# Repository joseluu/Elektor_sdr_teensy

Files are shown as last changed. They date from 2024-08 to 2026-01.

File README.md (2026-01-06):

### SDR front end for teensy and teensy audio

This frontend board stacks on top of a teensyaudio board which iself is stacked on the teensy.

<p align="center">
  <table style="width:100%">
    <tr>
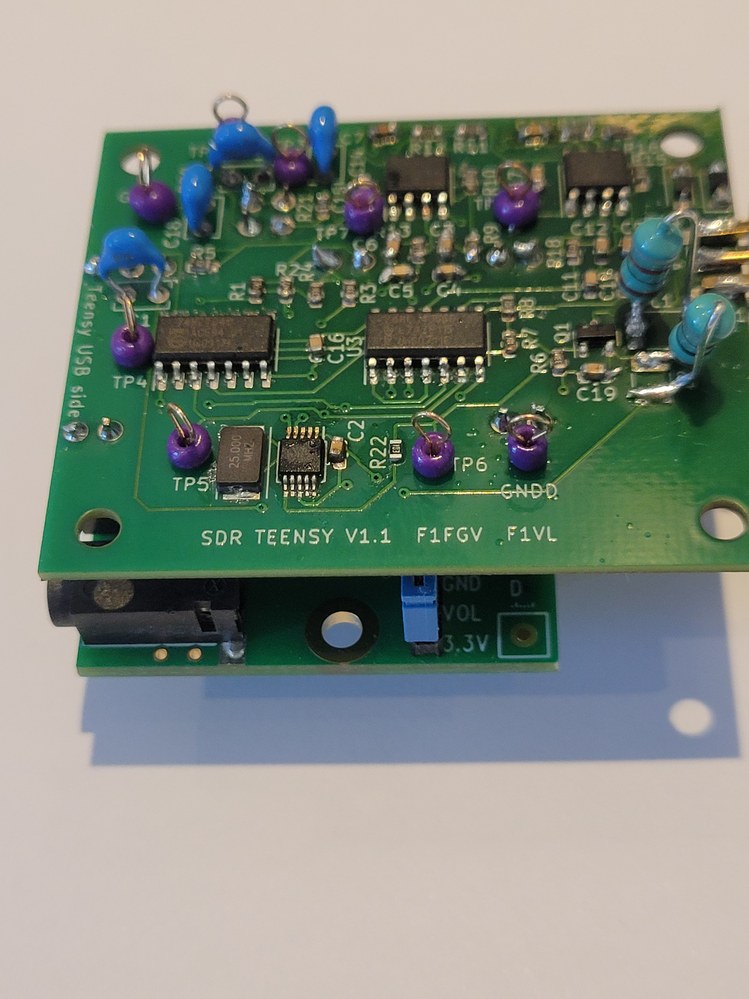
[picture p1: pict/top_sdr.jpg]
top view
      <td></td>
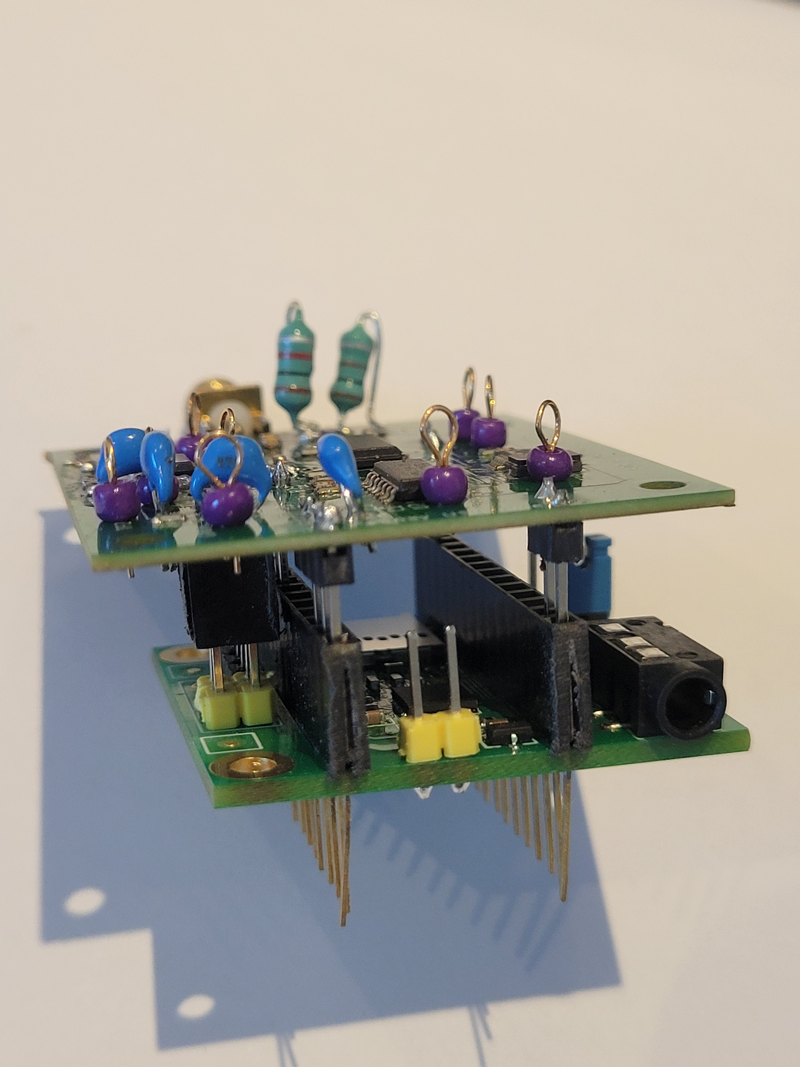
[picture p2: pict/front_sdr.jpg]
front view
      <td></td>
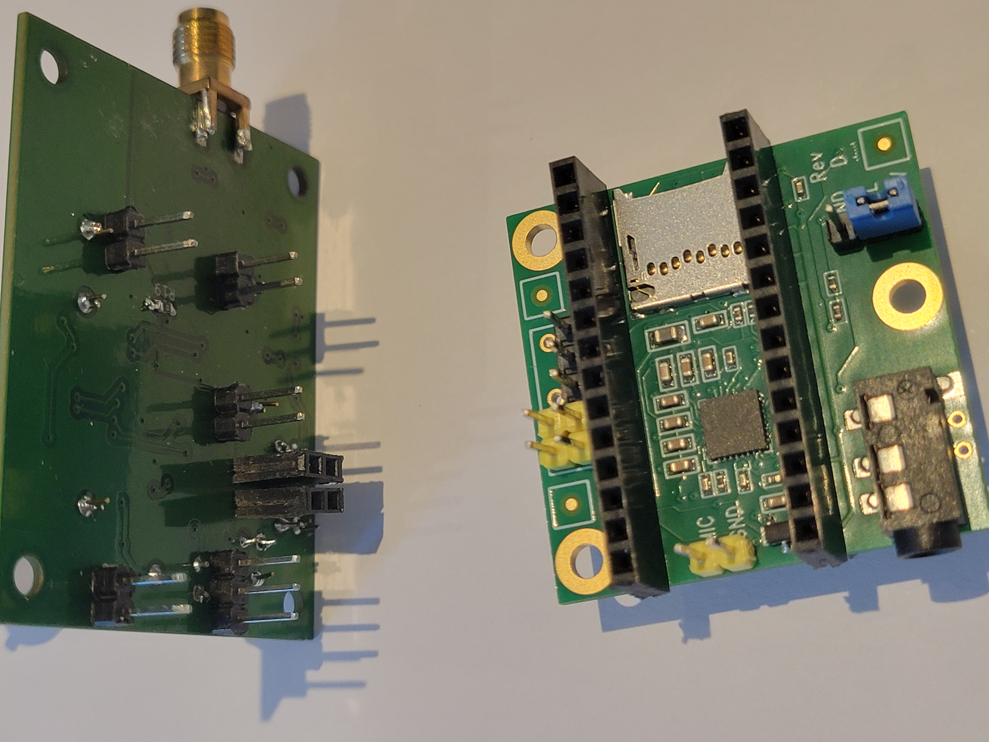
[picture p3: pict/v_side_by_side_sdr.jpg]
side by side view 1
      <td></td>
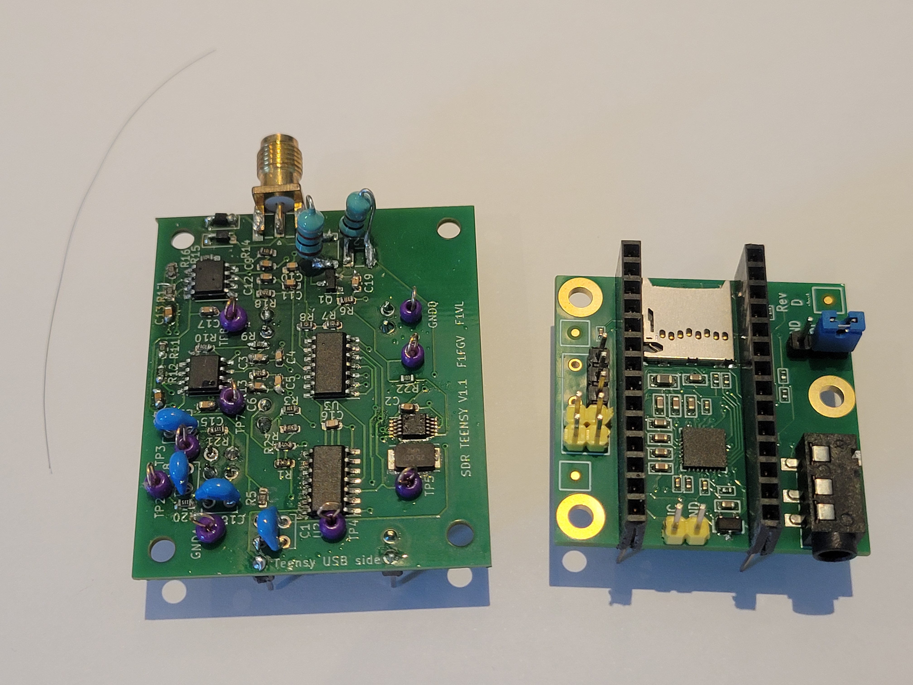
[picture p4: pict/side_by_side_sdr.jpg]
side by side view
      <td></td>
    </tr>
  </table>
</p>

Teensy 4.0 is used, schematic is heavily inspired by the Elektor board: https://www.elektormagazine.fr/labs/software-defined-radio-sdr-shield-for-arduino-150515-1

The differences are:

The frequency is not divided by 4 to make quadrature signals (no 7474 flipflops), rather the quadrature will have to be generated by the si5351.
A provision for an external oscillator input is made (V1.0 only), it uses a separate SMA

PCB layout attempts to minimize noise with separate ground planes for digital and analog

Versions (V2.0 is in its own branch):

<p align="center">
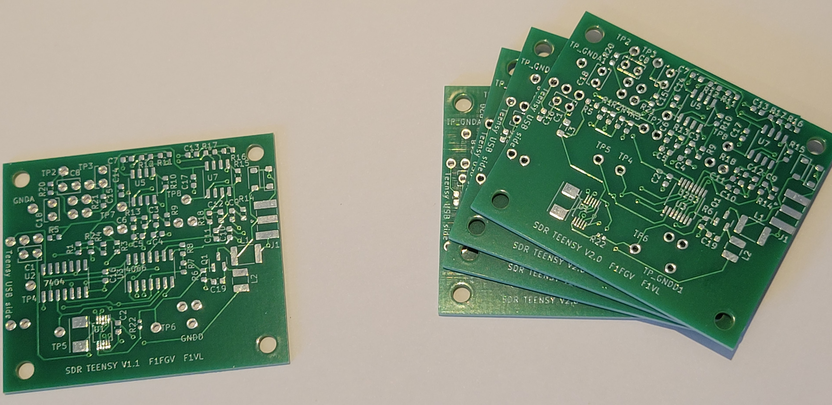
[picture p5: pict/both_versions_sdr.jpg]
both versions pcb
</td>
</p>

V 1.1 fixes a cabling error to two of the 6022 op-amps, removes the external oscillator input, internally connects the 3rd output of the si5351 frequency synthetiser to the input allowing fot tests and calibration of the signal path

V 1.1 uses a 74HC4066 multiplexer and is good to 30MHz, has a cabling error underneath where the zero ohm resistor connecting the 2 ground plane is not connected on one side.

V 2.0 uses a SN74CBTL3253 and should be good to 150MHz (work in progress, not tested yet)

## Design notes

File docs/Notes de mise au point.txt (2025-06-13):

Notes de mise au point:

Injecter signal de CLK2 sur l'entrée du récepteur, fréquence décalée de 50kHz, 
avec 50 db (1/300) d'atténuation -> 100mV crête (triangle) sur chacune des 2 entrées du shield audio

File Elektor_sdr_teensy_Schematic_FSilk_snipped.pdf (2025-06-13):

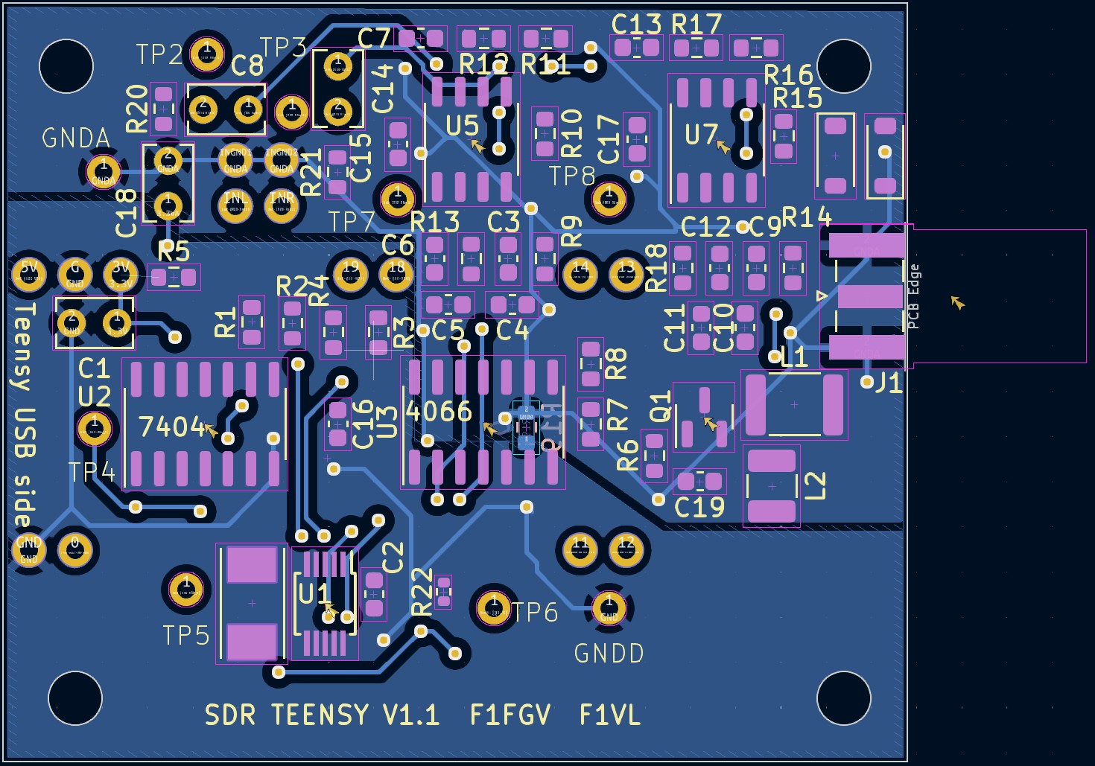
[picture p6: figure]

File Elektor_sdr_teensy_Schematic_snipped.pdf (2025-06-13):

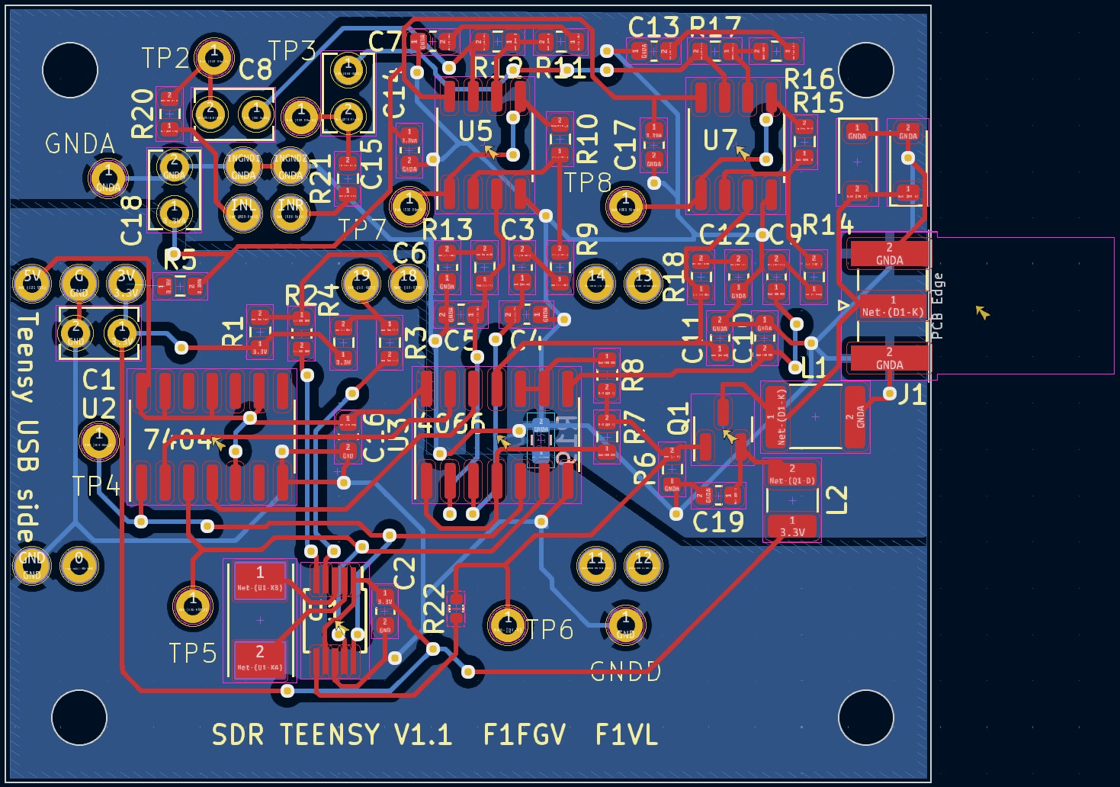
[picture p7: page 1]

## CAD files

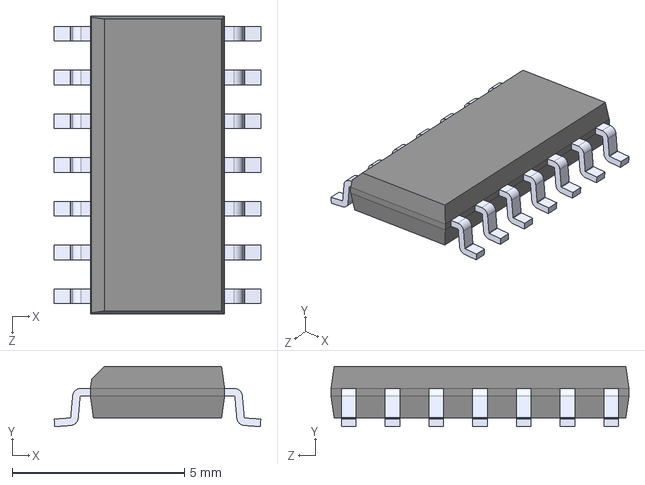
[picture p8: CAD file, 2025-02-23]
kicad_download/74HC4066D_653.step
6.00 x 1.75 x 8.65 mm

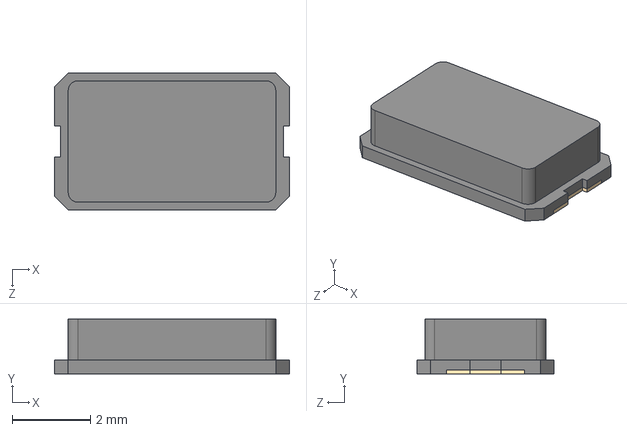
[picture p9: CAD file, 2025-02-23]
kicad_download/ABM7-16.000MHZ-D2Y-T.step
6.00 x 1.40 x 3.50 mm

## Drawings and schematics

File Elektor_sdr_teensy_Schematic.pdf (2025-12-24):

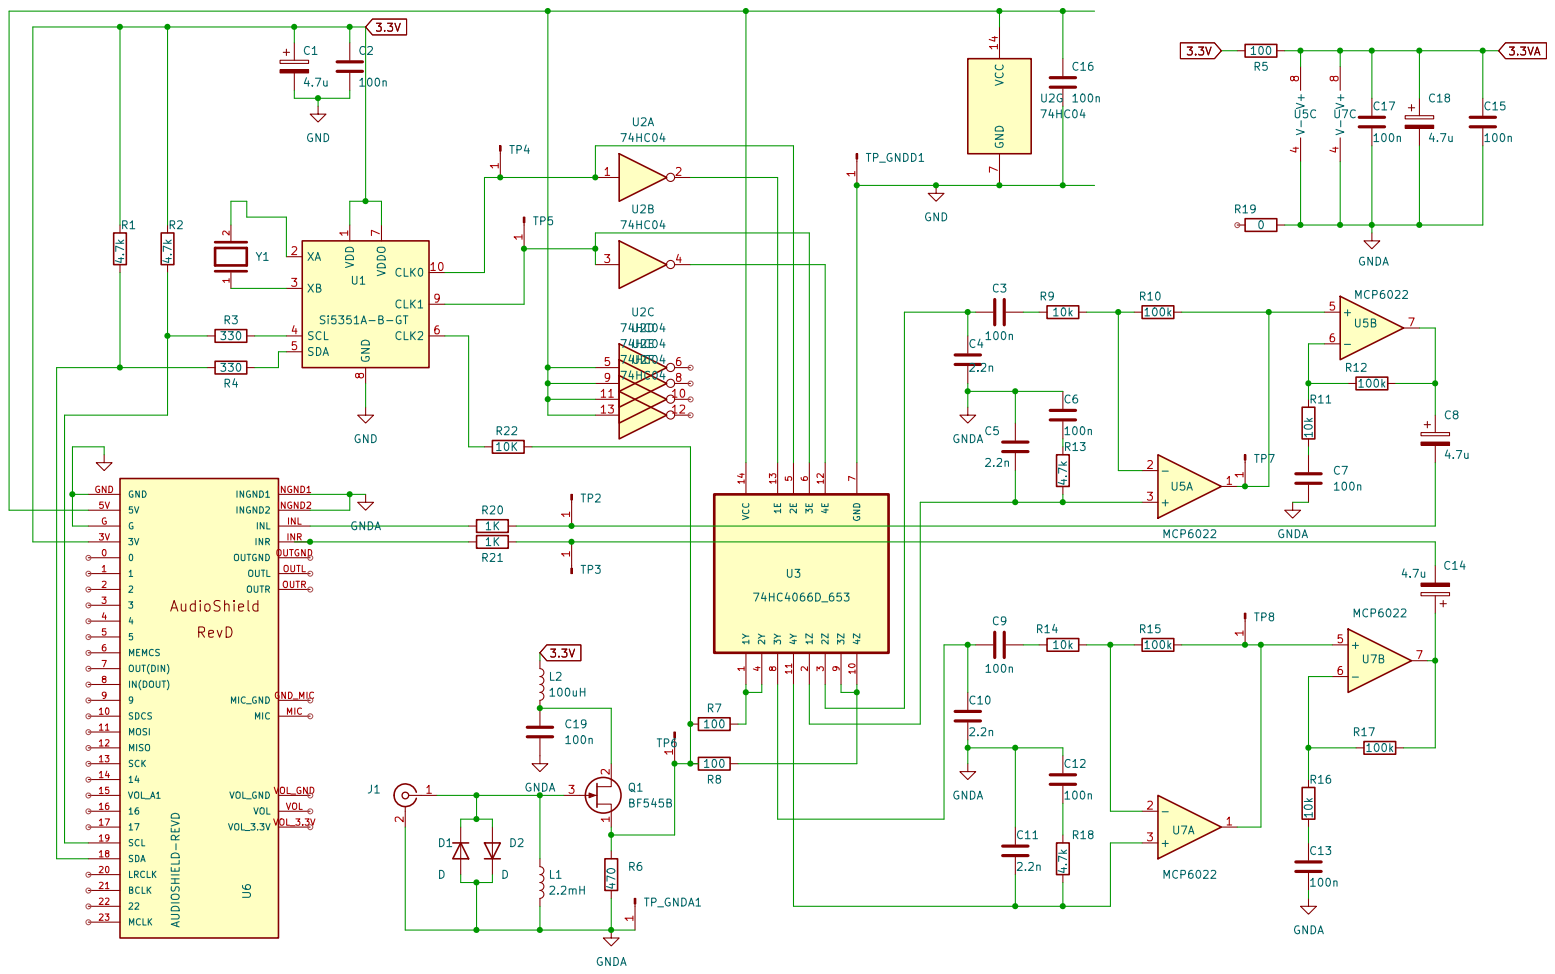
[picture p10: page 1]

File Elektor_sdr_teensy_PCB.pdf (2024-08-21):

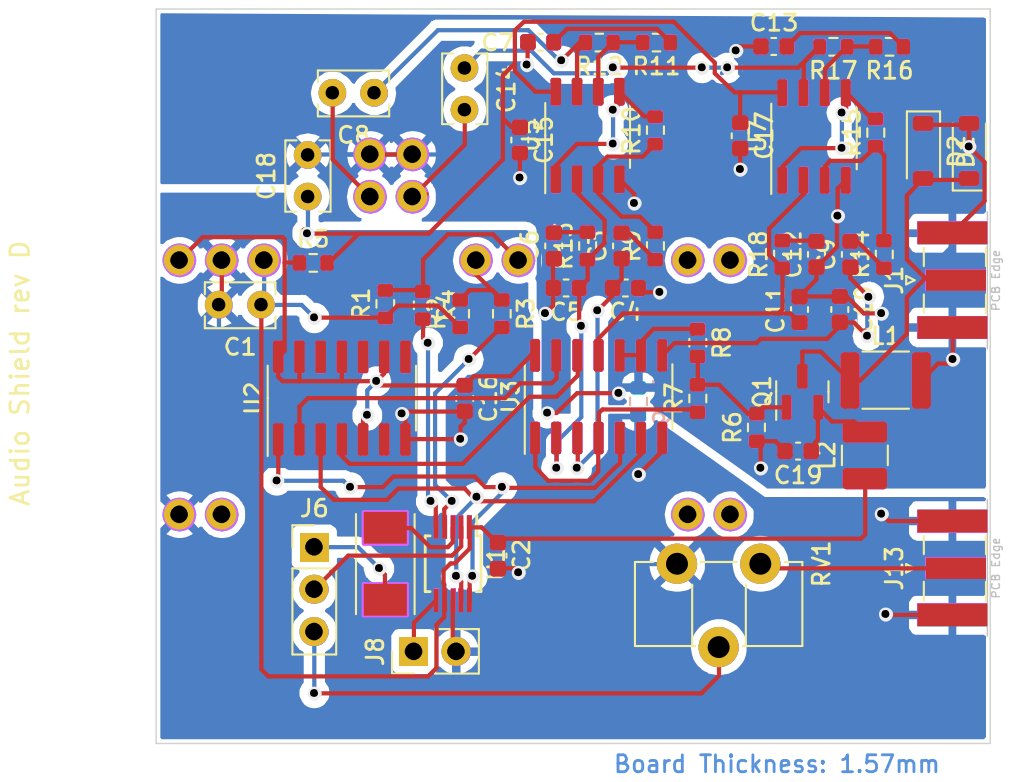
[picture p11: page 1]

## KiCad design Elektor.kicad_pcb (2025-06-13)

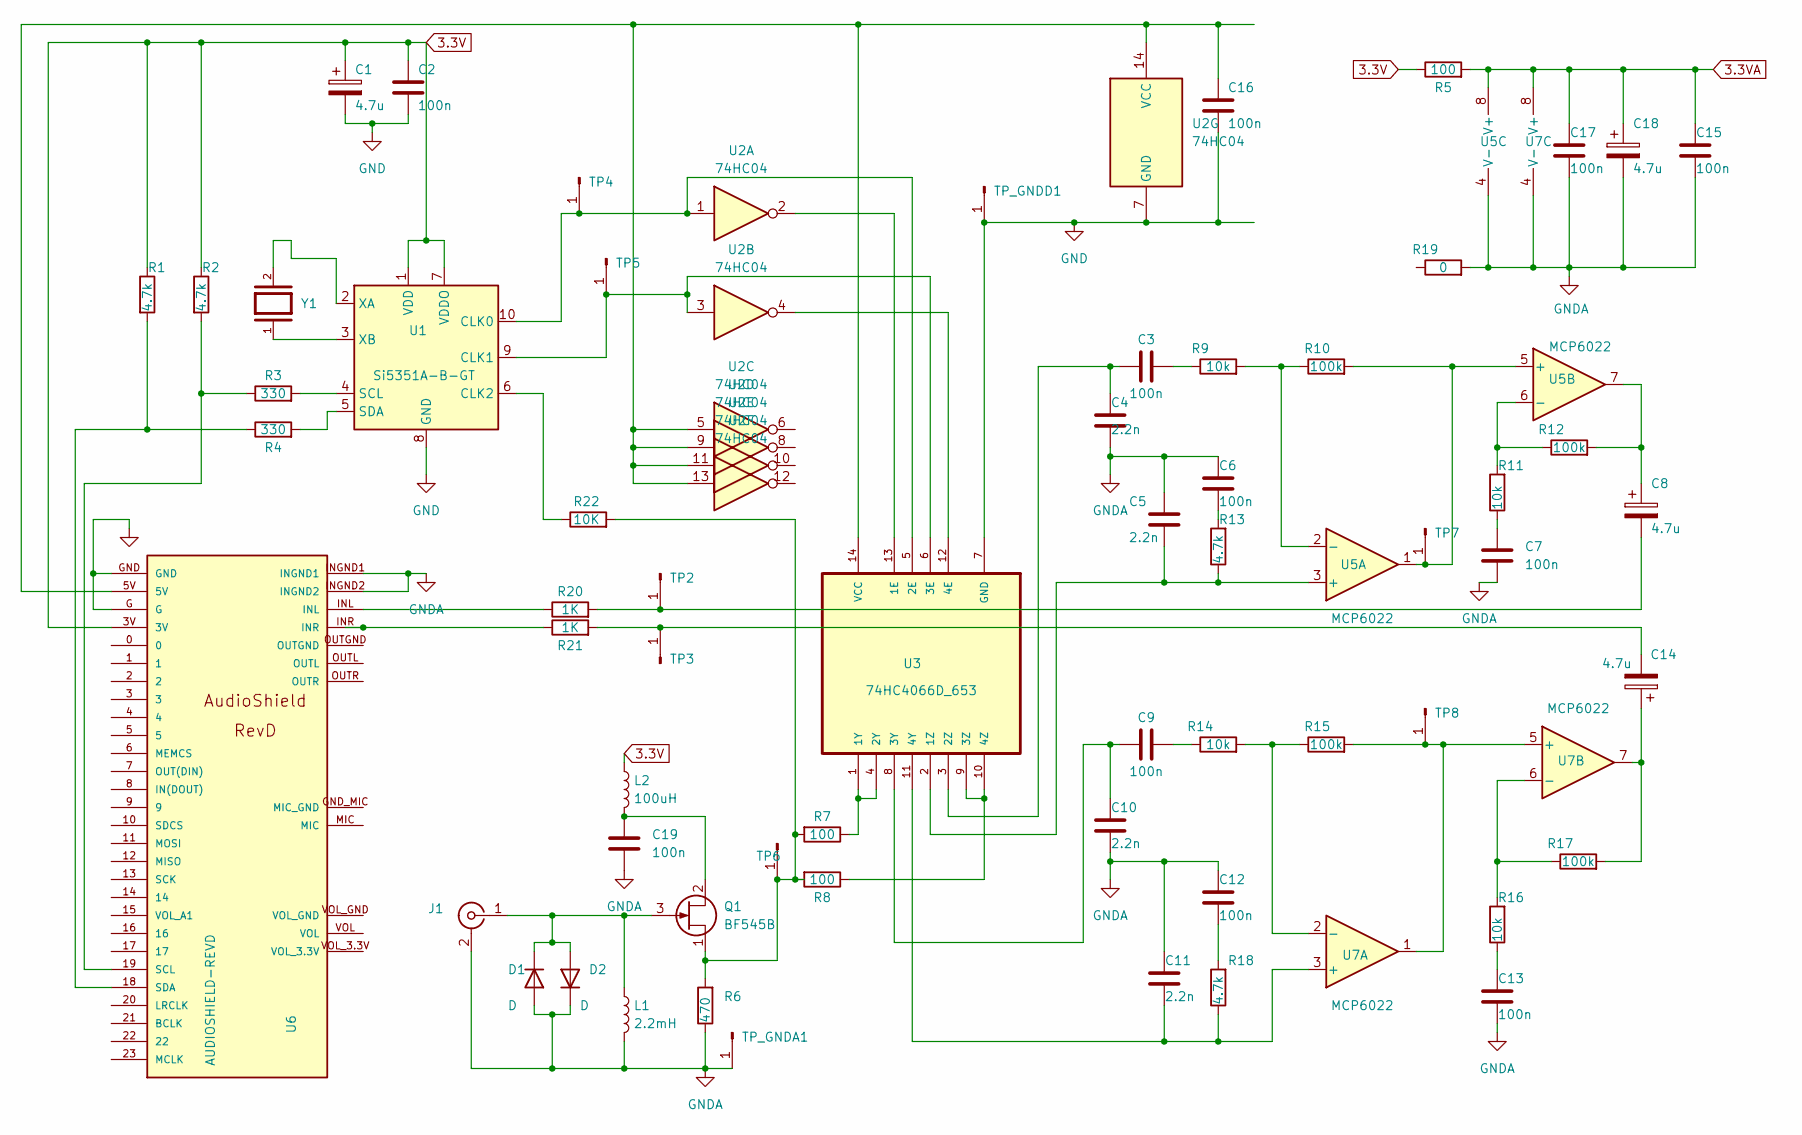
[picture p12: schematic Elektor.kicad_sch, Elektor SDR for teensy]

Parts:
C1, C8, C14, C18: 4.7u; C_Rect_L4.0mm_W2.5mm_P2.50mm
C2, C3, C6, C7, C9, C12, C13, C15, C16, C17, C19: 100n; C_0603_1608Metric
C4, C5, C10, C11: 2.2n; C_0603_1608Metric
D1, D2: D; D_SOD-123
J1: Conn_Coaxial; SMA_Samtec_SMA-J-P-X-ST-EM1_EdgeMount
L1: 2.2mH; L_1812_4532Metric
L2: 100uH; L_1210_3225Metric
Q1: BF545B; SOT-23
R1, R2, R13, R18: 4.7k; R_0603_1608Metric
R3, R4: 330; R_0603_1608Metric
R5, R7, R8: 100; R_0603_1608Metric
R6: 470; R_0603_1608Metric
R9, R11, R14, R16: 10k; R_0603_1608Metric
R10, R12, R15, R17: 100k; R_0603_1608Metric
R19: 0; R_0603_1608Metric
R20, R21: 1K; R_0603_1608Metric
R22: 10K; R_0402_1005Metric
TP2, TP3, TP4, TP5, TP6, TP7, TP8: Conn_01x01_Pin; Test_point_jose_D1.8mm_Drill1.0mm
TP_GNDA1: Conn_01x01_Pin; Test_point_jose_D1.8mm_Drill1.0mm
TP_GNDD1: Conn_01x01_Pin; Test_point_jose_D1.8mm_Drill1.0mm
U1: Si5351A-B-GT; MSOP-10_3x3mm_P0.5mm
U2: 74HC04; SOIC-14_3.9x8.7mm_P1.27mm
U3: 74HC4066D_653; SOIC-14_3.9x8.7mm_P1.27mm; MPN 74HC4066D,653
U5, U7: MCP6022; SOP-8_3.9x4.9mm_P1.27mm
U6: AUDIOSHIELD-REVD; AUDIOSHIELD-REVD-Simplified
Y1: ABM7-25.000MHZ-D2Y-T; XTAL_ABM7-16.000MHZ-D2Y-T; PARTREV 9/3/2019

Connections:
3.3V: C1.1, C2.1, L2.1, R1.1, R2.1, R5.1, U1.1 (VDD), U1.7 (VDDO), U6.3V
3.3VA: C15.1, C17.1, C18.1, R5.2, U5.8 (V+), U7.8 (V+)
GND: C1.2, C2.2, C16.2, TP_GNDD1.1, U1.8 (GND), U2.7 (GND), U3.7 (GND), U6.G, U6.GND; also elsewhere on the board
GNDA: C4.1, C5.2, C6.1, C7.1, C10.1, C11.2, C12.1, C13.1, C15.2, C17.2, C18.2, C19.2, D1.2 (A), D2.1 (K), J1.2 (Ext), L1.2, R6.1, R19.2, TP_GNDA1.1, U5.4 (V-), U6.INGND1, U6.INGND2, U7.4 (V-); also elsewhere on the board
unnamed: C3.2, R9.1
unnamed: C6.2, R13.2
unnamed: C7.2, R11.1
unnamed: C8.1, R12.2, U5.7
unnamed: C9.2, R14.1
unnamed: C12.2, R18.2
unnamed: C13.2, R16.1
unnamed: C14.1, R17.2, U7.7
unnamed: D1.1 (K), D2.2 (A), J1.1 (In), L1.1, Q1.3 (G)
unnamed: C19.1, L2.2, Q1.2 (D)
unnamed: Q1.1 (S), R6.2, R7.2, R8.2, R22.2, TP6.1
unnamed: R20.1, U6.INL
unnamed: R21.1, U6.INR
unnamed: C8.2, R20.2, TP2.1
unnamed: C14.2, R21.2, TP3.1
unnamed: TP4.1, U1.10 (CLK0), U2.1, U3.5 (2E)
unnamed: TP5.1, U1.9 (CLK1), U2.3, U3.6 (3E)
unnamed: R10.2, TP7.1, U5.1, U5.5 (+)
unnamed: R15.2, TP8.1, U7.1, U7.5 (+)
unnamed: R22.1, U1.6 (CLK2)
unnamed: R3.2, U1.4 (SCL)
unnamed: R4.2, U1.5 (SDA)
unnamed: U1.2 (XA), Y1.2
unnamed: U1.3 (XB), Y1.1
unnamed: C16.1, U2.5, U2.9, U2.11, U2.13, U2.14 (VCC), U3.14 (VCC), U6.5V
unnamed: U2.2, U3.13 (1E)
unnamed: R7.1, U3.1 (1Y), U3.4 (2Y)
unnamed: C5.1, R13.1, U3.2 (1Z), U5.3 (+)
unnamed: C3.1, C4.2, U3.3 (2Z)
unnamed: C9.1, C10.2, U3.8 (3Y)
unnamed: R8.1, U3.9 (3Z), U3.10 (4Z)
unnamed: U2.4, U3.12 (4E)
unnamed: C11.1, R18.1, U3.11 (4Y), U7.3 (+)
unnamed: R9.2, R10.1, U5.2 (-)
unnamed: R11.2, R12.1, U5.6 (-)
unnamed: R2.2, R3.1, U6.19 (SCL)
unnamed: R1.2, R4.1, U6.18 (SDA)
unnamed: R14.2, R15.1, U7.2 (-)
unnamed: R16.2, R17.1, U7.6 (-)

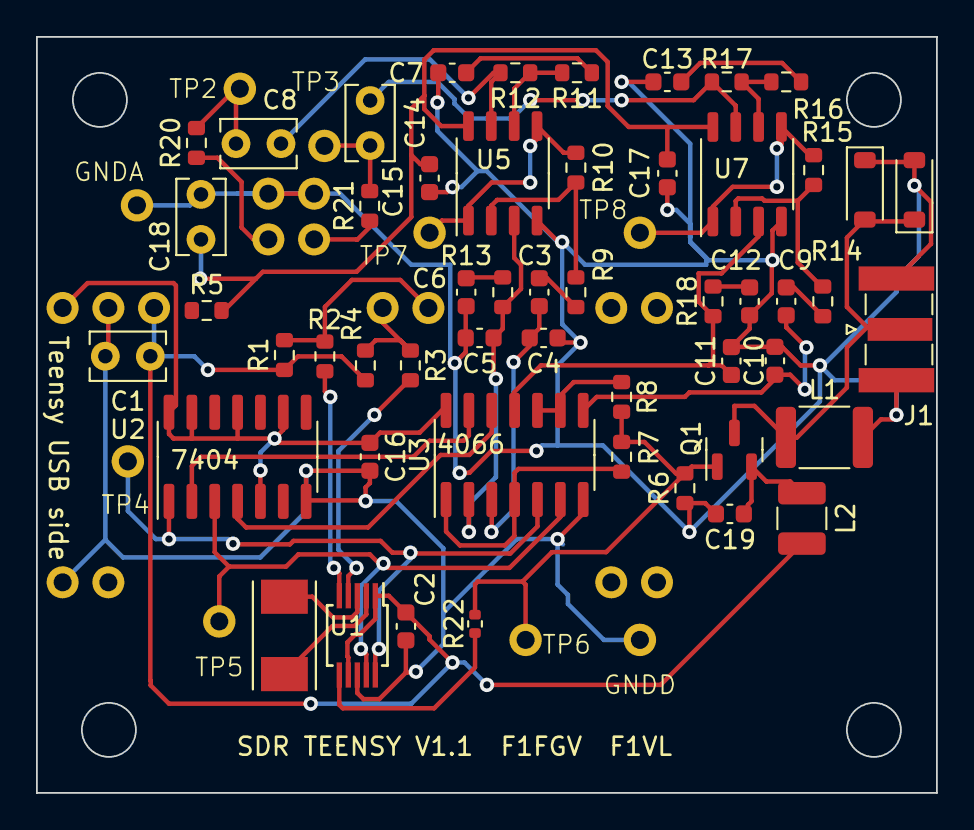
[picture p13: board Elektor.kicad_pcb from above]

Board: 2 copper layers, 50.0 x 42.0 mm, 63 parts (1 on the bottom side), 43 nets.

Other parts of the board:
GNDA: Conn_01x01_Pin; Test_point_jose_D1.8mm_Drill1.0mm
GNDD: Conn_01x01_Pin; Test_point_jose_D1.8mm_Drill1.0mm

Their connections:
GND: GNDD.1; also elsewhere on the board
GNDA: GNDA.1; also elsewhere on the board

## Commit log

2024-08-16 fix .gitignore
    [Elektor.kicad_pcb, Elektor.kicad_sch]
2024-08-19 routage plus compact
    [Elektor.kicad_pcb, Elektor.kicad_sch]
2024-08-20 avec plan de masse
    [Elektor.kicad_pcb]
2024-08-20 meilleur plan de masse
    [Elektor.kicad_pcb]
2024-08-21 plus compact
    [Elektor.kicad_pcb, Elektor.kicad_sch]
2024-08-21 ajout connexion manquante
    [Elektor.kicad_pcb]
2024-08-21 4066 avait 16 broches au lieu de 14 !
    [Elektor.kicad_pcb, Elektor.kicad_sch]
2025-02-23 debut V2
    [74HC4066D_653.step, ABM7-16.000MHZ-D2Y-T.step, Elektor.kicad_sch]
2025-06-13 release V1.1
    [Elektor-B_Cu.gbr, Elektor-B_Mask.gbr, Elektor-B_Paste.gbr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]
2025-12-24 correct pdf schematic
2026-01-06 make kicad langage recognized by github
